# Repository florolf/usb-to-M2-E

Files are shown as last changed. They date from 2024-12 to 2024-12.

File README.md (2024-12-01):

# USB ⇔ M.2-E

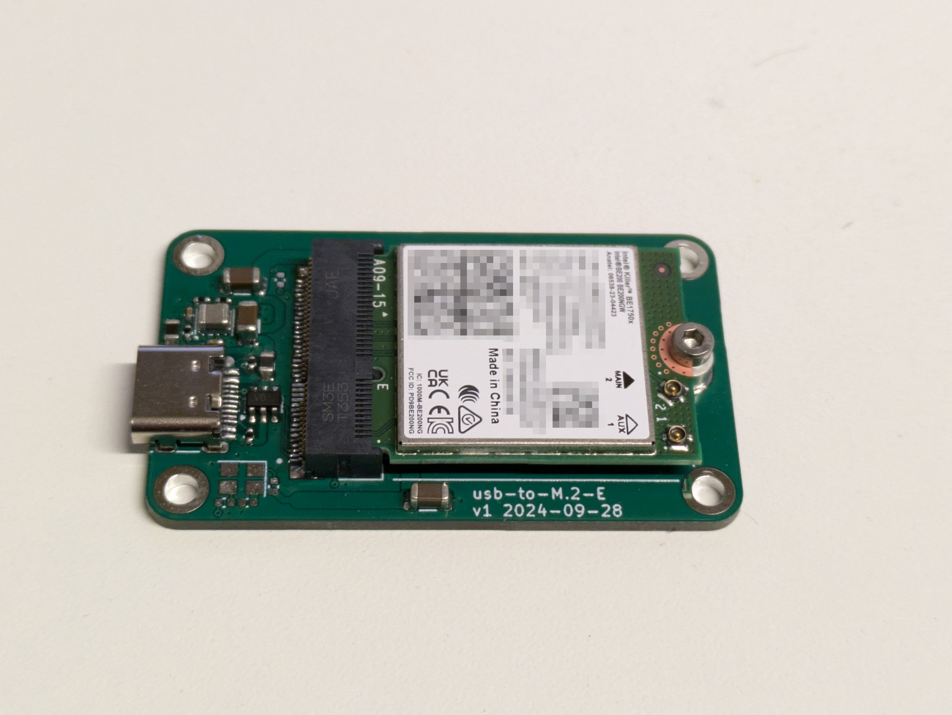
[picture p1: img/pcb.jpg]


## Why?

I wanted an USB Bluetooth dongle with support for recent Bluetooth versions (and LE Isochronous Channels in particular, while still supporting Bluetooth Classic) with Linux support that isn't excessively painful, which rules out basically every off-the-shelf dongle in existence.

Intel WiFi cards have excellent Bluetooth support, but they come in the form of M.2 cards which are meant to be installed internally. The aim of this project was to answer the question whether those cards would still work if only the Bluetooth component (which uses USB, unlike the WiFi part which attaches through PCIe) was active. The answer turned out to be yes (see [below](#compatibilty) for known-working cards).

## What is it?

It's a simple PCB that contains:

 * An USB-C receptacle
 * A 5V → 3.3V voltage regulator
 * A M.2 E-key socket
 * Optionally a SUSCLK oscillator

Only the USB section of the M.2 interface is connected.

## Fabrication

This is a basic 1.6mm 2 layer board that should be manufacturable almost anywhere. I used JLCPCB, you can find the Gerbers in the [`generated/fab`](generated/fab/) directory and a BOM in [`generated/bom.csv`](generated/bom.csv).

## Compatibility

This section lists cards that are known to work with this adapter:

 * Intel Killer BE1750x (Bluetooth uses the `AUX` antenna)

Note that most Intel WiFi cards also come in a CNVio variant that uses the same connector, but uses it in a non-standard fashion. It is unknown if those cards would work with this adapter.

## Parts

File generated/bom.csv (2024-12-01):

Reference | Value | Datasheet | Footprint | Qty | Digikey
J1 | USB_C_Receptacle_USB2.0_16P | https://www.usb.org/sites/default/files/documents/usb_type-c.zip | Connector_USB:USB_C_Receptacle_HRO_TYPE-C-31-M-12 | 1
C2,C5,C6 | 22u | ~ | Capacitor_SMD:C_1206_3216Metric | 3
C1,C3,C4 | 100n | ~ | Capacitor_SMD:C_0402_1005Metric | 3
R7 | 24k | ~ | Resistor_SMD:R_0402_1005Metric | 1
R6 | 75k | ~ | Resistor_SMD:R_0402_1005Metric | 1
R4 | 33R | ~ | Resistor_SMD:R_0402_1005Metric | 1
R3,R5,R8 | 10k | ~ | Resistor_SMD:R_0402_1005Metric | 3
R1,R2 | 5k1 | ~ | Resistor_SMD:R_0402_1005Metric | 2
J2 | Bus_M.2_Socket_E | https://www.jae.com/direct/topics/topics_file_download/?topics_id=68917&ext_no=04&_lang=en | local:JAE_SM3ZS067UxxM | 1 | 670-2692-1-ND
U2 | TPS82140 | http://www.ti.com/lit/ds/symlink/tps82140.pdf | Package_LGA:Texas_SIL0008D_MicroSiP-8-1EP_2.8x3mm_P0.65mm_EP1.1x1.9mm_ThermalVias | 1 | 296-48215-1-ND
X1 | 32.768kHz | https://ecsxtal.com/store/pdf/ECS_327KE.pdf | Crystal:Crystal_SMD_3225-4Pin_3.2x2.5mm | 1 | XC1751CT-ND
U1 | SRV05-4 |  | Package_TO_SOT_SMD:SOT-23-6 | 1 | SRV05-4L-TPMSCT-ND
FB1,FB2 | 120R @ 100MHz | https://www.fair-rite.com/wp-content/themes/fair-rite/print_product.php?pid=19226 | Inductor_SMD:L_0805_2012Metric | 2 | 1934-1472-1-ND

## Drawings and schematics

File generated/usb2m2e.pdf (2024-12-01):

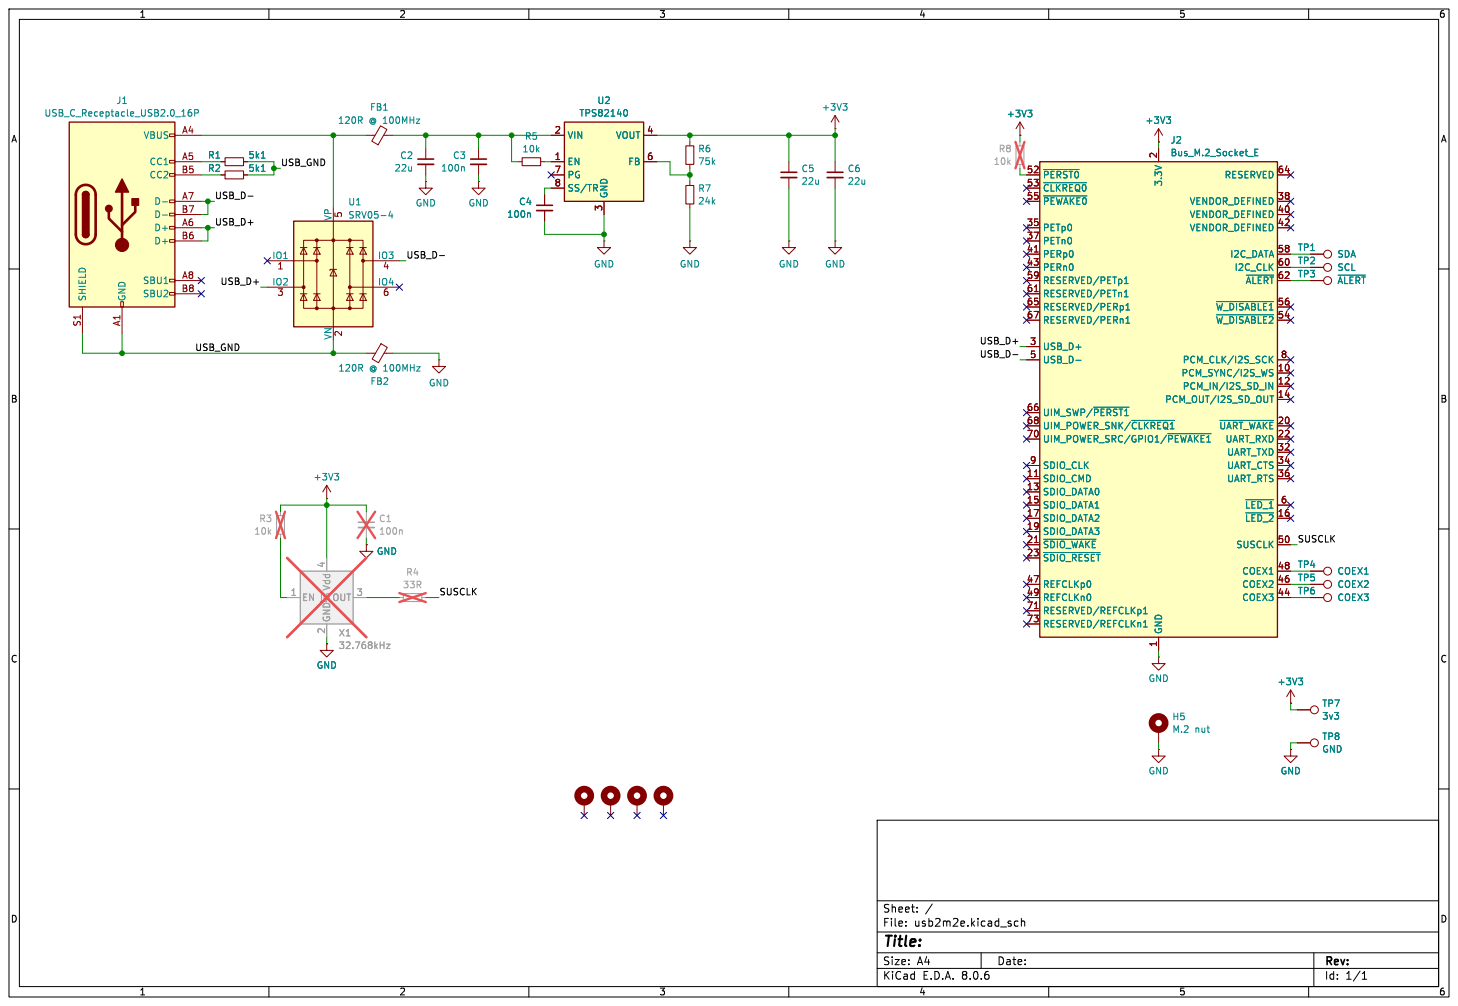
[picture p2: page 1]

3 VOUT 4 FB 6 PG 7 SS/TR 8 U2 TPS82140 R4

3 VOUT 4 FB 6 PG 7 SS/TR 8

Id: 1/1 Title: File: usb2m2e.kicad_sch Sheet: /

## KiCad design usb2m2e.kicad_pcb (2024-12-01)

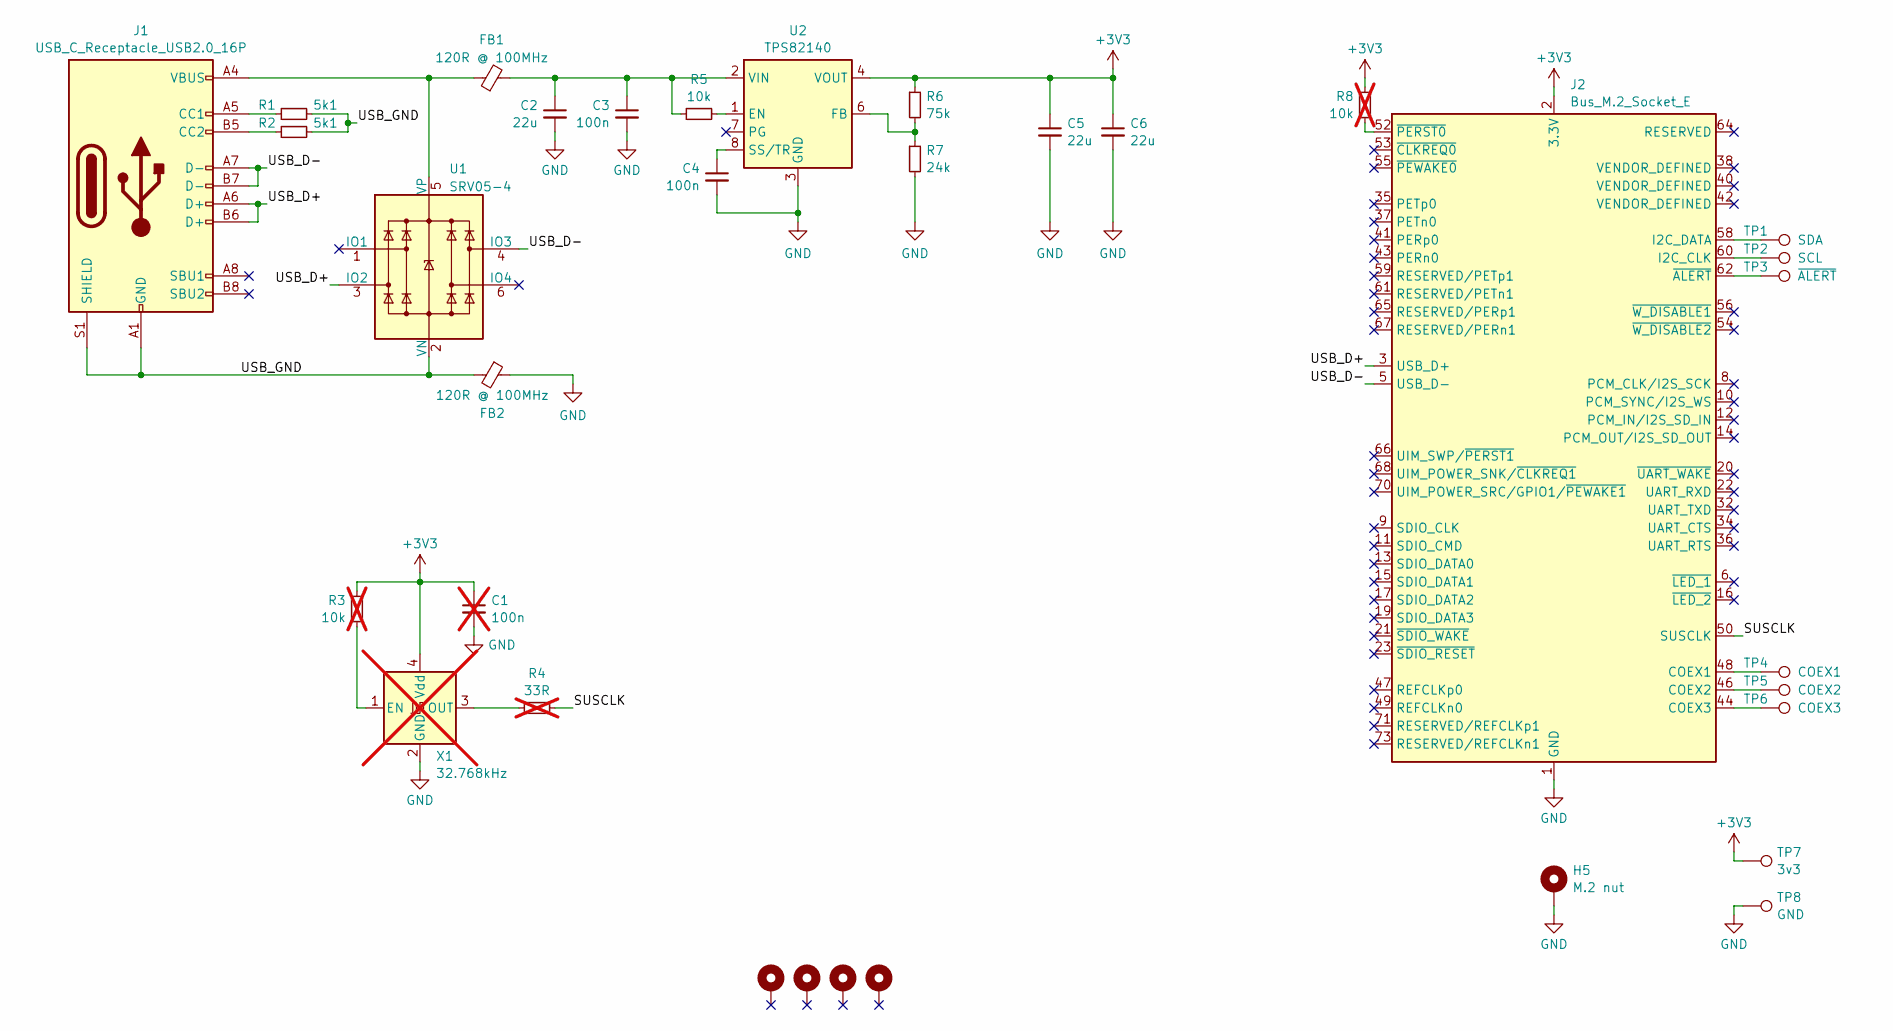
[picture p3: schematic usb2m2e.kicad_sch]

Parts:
C1: 100n; C_0402_1005Metric; not fitted
C2, C5, C6: 22u; C_1206_3216Metric
C3, C4: 100n; C_0402_1005Metric
FB1, FB2: 120R @ 100MHz; L_0805_2012Metric; MPN 2508051217Y6; Digikey 1934-1472-1-ND
H1, H2, H3, H4: MountingHole_Pad; MountingHole_2.7mm_M2.5_ISO14580_Pad
H5: M.2 nut; JAE_SM3ZS067Uxxx-NUT1; MPN SM3ZS067U410-NUT1-R1200; Digikey 670-2865-1-ND
J1: USB_C_Receptacle_USB2.0_16P; USB_C_Receptacle_HRO_TYPE-C-31-M-12
J2: Bus_M.2_Socket_E; JAE_SM3ZS067UxxM; MPN SM3ZS067U410AER1000; Digikey 670-2692-1-ND
R1, R2: 5k1; R_0402_1005Metric
R3, R8: 10k; R_0402_1005Metric; not fitted
R4: 33R; R_0402_1005Metric; not fitted
R5: 10k; R_0402_1005Metric
R6: 75k; R_0402_1005Metric
R7: 24k; R_0402_1005Metric
TP1: SDA; TestPoint_Pad_D1.5mm
TP2: SCL; TestPoint_Pad_D1.5mm
TP3: ~{ALERT}; TestPoint_Pad_D1.5mm
TP4: COEX1; TestPoint_Pad_D1.5mm
TP5: COEX2; TestPoint_Pad_D1.5mm
TP6: COEX3; TestPoint_Pad_D1.5mm
TP7: 3v3; TestPoint_Pad_D1.5mm
TP8: GND; TestPoint_Pad_D1.5mm
U1: SRV05-4; SOT-23-6; MPN SRV05-4L-TP; Digikey SRV05-4L-TPMSCT-ND
U2: TPS82140; Texas_SIL0008D_MicroSiP-8-1EP_2.8x3mm_P0.65mm_EP1.1x1.9mm_T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; MPN TPS82140SIL; Digikey 296-48215-1-ND
X1: 32.768kHz; Crystal_SMD_3225-4Pin_3.2x2.5mm; MPN ECS-327KE-TR; Digikey XC1751CT-ND; not fitted

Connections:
+3V3: C1.1, C5.1, C6.1, J2.2 (3.3V), J2.4 (3.3V), J2.72 (3.3V), J2.74 (3.3V), R3.1, R6.1, R8.1, TP7.1, U2.4 (VOUT), U2.5 (VOUT), X1.4 (Vdd)
/SUSCLK: J2.50 (SUSCLK), R4.2
/USB_D+: J1.A6 (D+), J1.B6 (D+), J2.3 (USB_D+), U1.3 (IO2)
/USB_D-: J1.A7 (D-), J1.B7 (D-), J2.5 (USB_D-), U1.4 (IO3)
/USB_GND: FB2.2, J1.A1 (GND), J1.A12 (GND), J1.B1 (GND), J1.B12 (GND), J1.S1 (SHIELD), R1.2, R2.2, U1.2 (VN)
GND: C1.2, C2.2, C3.2, C4.2, C5.2, C6.2, FB2.1, H5.1, J2.1 (GND), J2.7 (GND), J2.18 (GND), J2.33 (GND), J2.39 (GND), J2.45 (GND), J2.51 (GND), J2.57 (GND), J2.63 (GND), J2.69 (GND), J2.75 (GND), R7.2, TP8.1, U2.3 (GND), U2.9 (GND), X1.2 (GND)
unnamed: J1.A5 (CC1), R1.1
unnamed: J1.B5 (CC2), R2.1
unnamed: J2.48 (COEX1), TP4.1
unnamed: J2.46 (COEX2), TP5.1
unnamed: J2.44 (COEX3), TP6.1
unnamed: J2.60 (I2C_CLK), TP2.1
unnamed: J2.58 (I2C_DATA), TP1.1
unnamed: J2.62 (~ALERT), TP3.1
unnamed: J2.52 (~PERST0), R8.2
unnamed: FB1.1, J1.A4 (VBUS), J1.A9 (VBUS), J1.B4 (VBUS), J1.B9 (VBUS), U1.5 (VP)
unnamed: R5.2, U2.1 (EN)
unnamed: R6.2, R7.1, U2.6 (FB)
unnamed: C4.1, U2.8 (SS/TR)
unnamed: C2.1, C3.1, FB1.2, R5.1, U2.2 (VIN)
unnamed: R3.2, X1.1 (EN)
unnamed: R4.1, X1.3 (OUT)

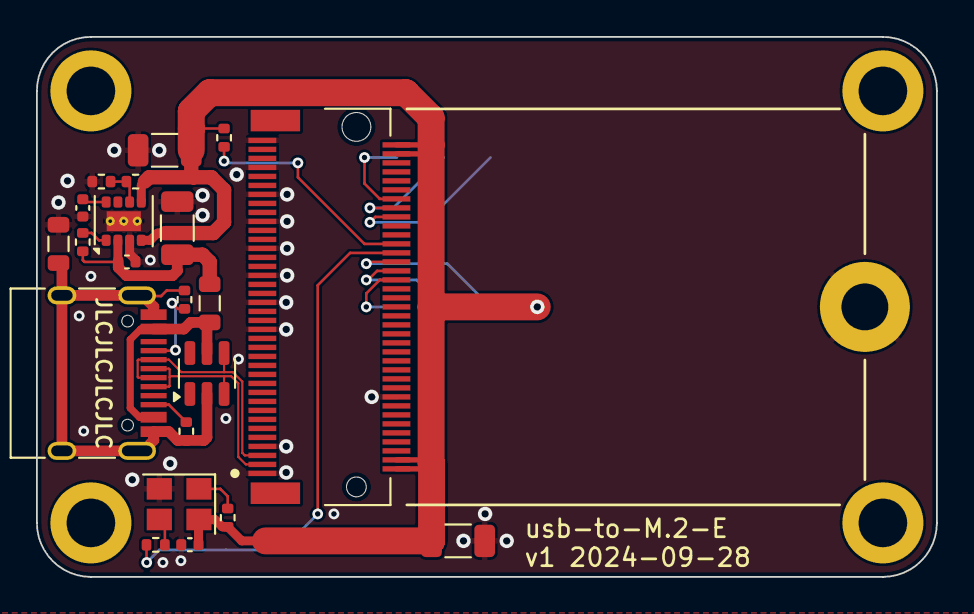
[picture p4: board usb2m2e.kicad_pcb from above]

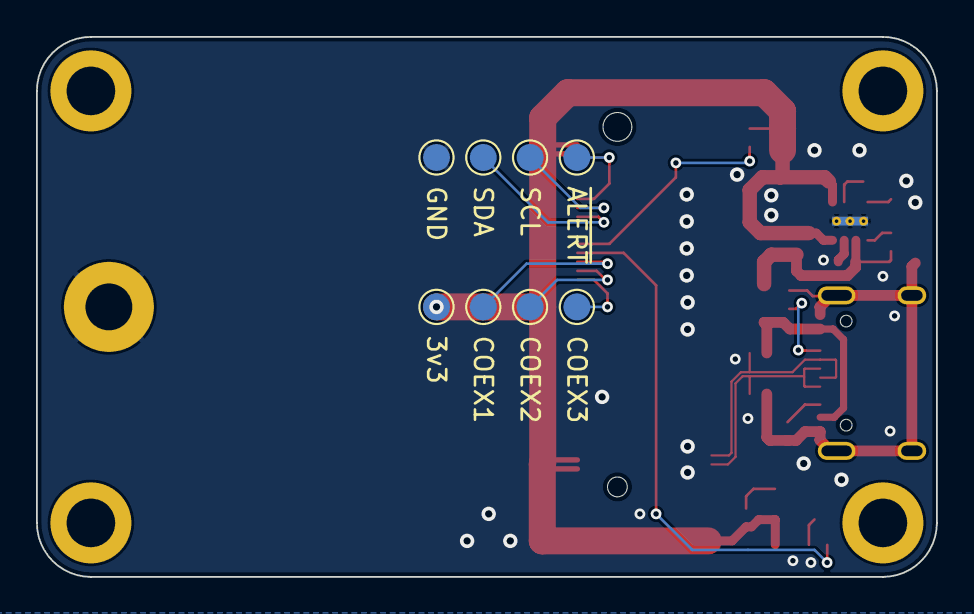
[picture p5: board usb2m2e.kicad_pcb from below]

Board: 2 copper layers, 50.0 x 30.0 mm, 34 parts (8 on the bottom side), 22 nets.
